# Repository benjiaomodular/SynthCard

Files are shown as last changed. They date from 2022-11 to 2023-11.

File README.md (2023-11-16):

# SynthCard
A businesscard-sized synthesizer module based on the Atari Punk Console.

I designed this project with the help of PCBWay. You can get a copy of these cards through the [PCBWay Shared Projects page](https://www.pcbway.com/project/shareproject/SynthCard_A_business_card_sized_synthesizer_module_84514b6e.html).

Schematics under `/KiCAD`. Gerber files under `/Fabrication`. Panel design under `/Inkscape`.

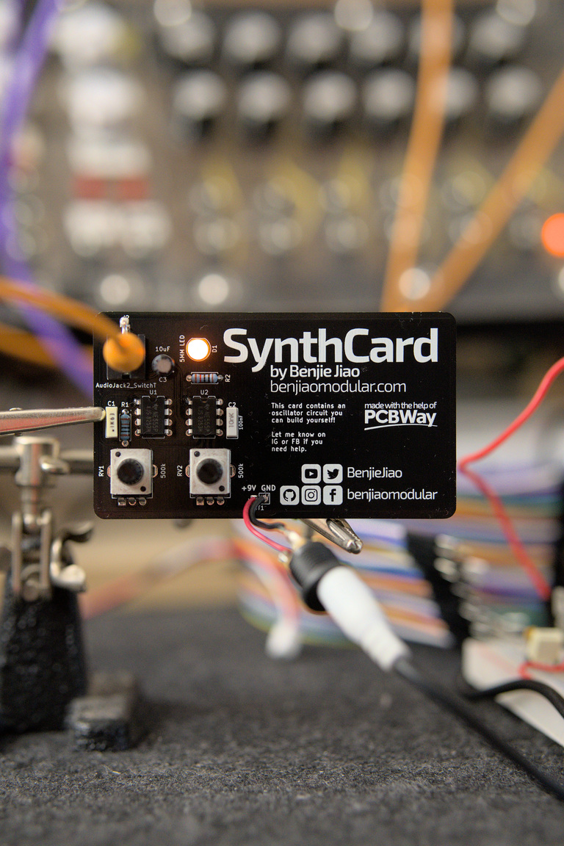
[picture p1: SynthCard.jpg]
A fully assembled SynthCard


## Features

This module produces a pulse/square wave at 9Vpp.

There are two knobs. Knob 1 controls the frequency. Knob 2 controls the pulse width.

The module can be powered using a 9V power supply. A battery should work too.

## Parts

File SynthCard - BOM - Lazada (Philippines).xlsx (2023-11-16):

Reference | Quantity | Value | Part Description | Cost | Lazada Link
BT1 | 1 | Battery | 9V Battery Snap or Barrel Connector | 64 | https://www.lazada.com.ph/products/10-pcs-3-terminal-soldering-21mm-x-55mm-female-power-jack-dc-socket-i3351654734.html
C1 | 1 | 10nF | Film Capacitors 50volts 0.01uF 10% LS 5mm | 6 | https://www.lazada.com.ph/products/polyester-film-capacitor-100v-mylar-022nf-033nf-047nf-056nf-068nf-1nf-22nf-27nf-33nf-39nf-47nf-68nf-10nf-15nf-22nf-33nf-39n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
C2 | 1 | 100nF | Film Capacitors 50volts 0.1uF 10% LS 5mm | 7 | https://www.lazada.com.ph/products/polyester-film-capacitor-100v-mylar-022nf-033nf-047nf-056nf-068nf-1nf-22nf-27nf-33nf-39nf-47nf-68nf-10nf-15nf-22nf-33nf-39n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
C3 | 1 | 10uF | Aluminum Electrolytic Capacitors - Radial Leaded 25volts 10uF | 4 | https://www.lazada.com.ph/products/aluminum-electrolytic-capacitor-10v-16v-25v-50v-01uf-022uf-047uf-1uf-22uf-33uf-47uf-68uf-10uf-22uf-33uf-47uf-100uf-220uf-33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
D1 | 1 | 5MM LED | Standard 5MM LED, any color will do | 40 | https://www.lazada.com.ph/products/20pcs-pack-3mm-5mm-led-light-diode-red-blue-green-white-yellow-2-pins-light-emitting-diode-3v-dc-dip-bead-lighting-f3-f5-3-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
J2 | 1 | 3.5mm Audio Jack | 3.5mm Mono Jack | 229 | https://www.lazada.com.ph/products/50pcs-35mm-female-audio-connector-3-pin-dip-headphone-jack-socket-mono-channel-pj-301m-wholesale-i385302560.html
R1 | 1 | 1k | 1/4W Resistor 1k ohms | 20 | https://www.lazada.com.ph/products/50pcs-1k-ohms-14w-metal-film-resistors-pack-1kohms-025w-watt-1-tolerance-1000r-electronic-part-ohm-5-bands-1-k-i857644178.h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
R2 | 1 | 10k | 1/4W Resistor 10k ohms | 20 | https://www.lazada.com.ph/products/50pcs-10k-ohms-14w-metal-film-resistors-pack-10-k-ohm-025w-watt-1-tolerance-10k-r-i864070514.html
RV1 RV2 | 2 | 500k | 500k Potentiometers. Also try 100k and 1M for different response and range. | 114 | https://www.lazada.com.ph/products/5set10pcs-rv09-vertical-1k-500k-ohm-adjustable-resistor-3pin-seal-potentiometer-for-arduino-with-knob-white-cap-5pcs5pcs-i3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
U1 U2 | 2 | NE555P | Timers & Support Products | 68 | https://www.lazada.com.ph/products/diymore-10pcs50pcs-lot-ne555-ne-555-ne555p-dip-8-dip-8-single-bipolar-timers-ic-chip-diymore-i1118752497.html
Wire | 1 | 24 AWG | 24 AWG Stranded Copper Wire | 10 | https://www.lazada.com.ph/products/stranded-solid-wire-22-24-awg-1meter-electrical-copper-cable-led-audio-diy-electronics-projects-electrical-i2205435323.html
 |  |  | TOTAL | 582

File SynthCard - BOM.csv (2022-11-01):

Reference | Quantity | Value | Footprint | Datasheet | Type | Manufacturers Name | Manufacturers Part Number | Part Description | Package
BT1 | 1 | Battery | Connector_PinHeader_2.54mm:PinHeader_1x02_P2.54mm_Vertical |  | Through-hole
C1 | 1 | 10nF | benjiaomodular:Capacitor_Rect_L7.2mm_W2.5mm_P5.00mm |  | Through-hole | KEMET | MMK5103K50J01L4BULK | Film Capacitors 50volts 0.01uF 10% LS 5mm
C2 | 1 | 100nF | benjiaomodular:Capacitor_Rect_L7.2mm_W2.5mm_P5.00mm |  | Through-hole | KEMET | MMK5104K50J01L4BULK | Film Capacitors 50volts 0.1uF 10% LS 5mm
C3 | 1 | 10uF | benjiaomodular:Capacitor_Radial_D5.0mm_P2.5mm |  | Through-hole | Nichicon | UVR1E100MDD1TD | Aluminum Electrolytic Capacitors - Radial Leaded 25volts 10uF
D1 | 1 | 5MM LED | LED_THT:LED_D5.0mm |  | Through-hole
J2 | 1 | AudioJack2_SwitchT | benjiaomodular:AudioJack_3.5mm |  | Through-hole | Tayda Electronics | PJ-3001F
R1 | 1 | 1k | benjiaomodular:Resistor_L6.3mm_D2.5mm_P7.62mm_Horizontal |  | Through-hole | KOA Speer | MF1/4DCT26A1001F
R2 | 1 | 10k | benjiaomodular:Resistor_L6.3mm_D2.5mm_P7.62mm_Horizontal |  | Through-hole | KOA Speer | MF1/4DC1002F
RV1 RV2 | 2 | 500k | benjiaomodular:Potentiometer_RV09 |  | Through-hole | Alpha (Taiwan) | RV09AF-40-20K-B500K
U1 U2 | 2 | NE555P | Package_DIP:DIP-8_W7.62mm | http://www.ti.com/lit/ds/symlink/ne555.pdf | Through-hole | Texas Instruments | NE555P | Timers & Support Products | PDIP-8

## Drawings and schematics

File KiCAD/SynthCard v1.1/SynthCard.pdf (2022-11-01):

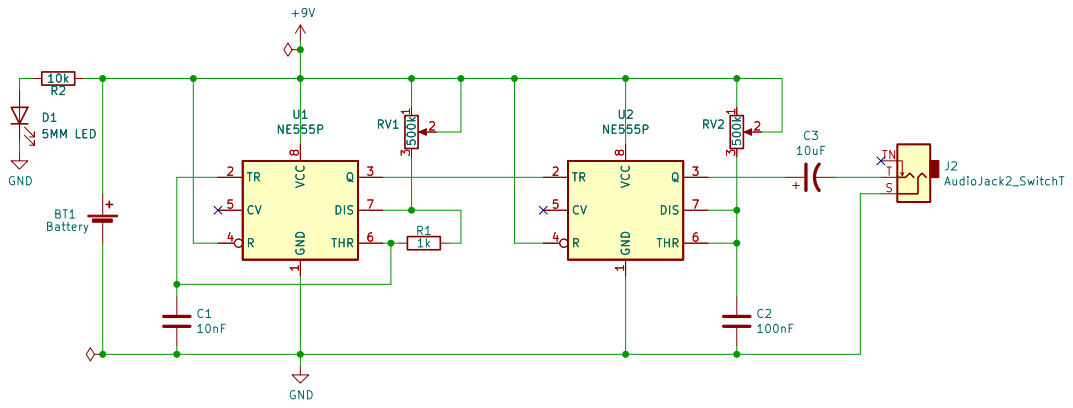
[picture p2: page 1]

File: SynthCard.kicad_sch Sheet: / GND

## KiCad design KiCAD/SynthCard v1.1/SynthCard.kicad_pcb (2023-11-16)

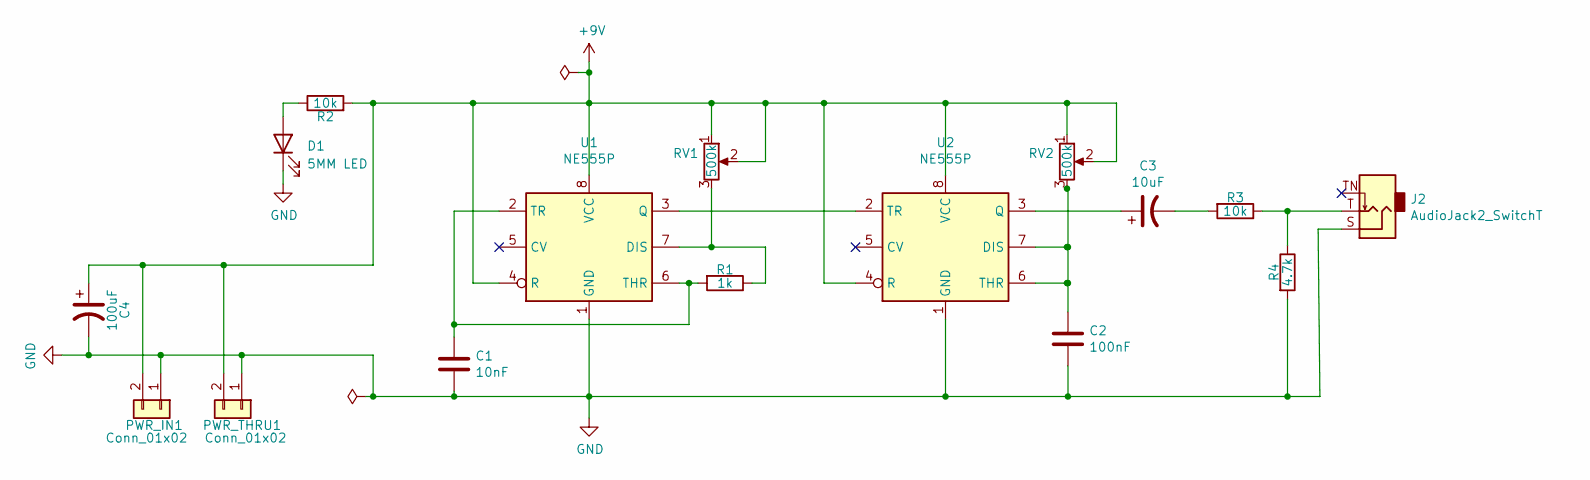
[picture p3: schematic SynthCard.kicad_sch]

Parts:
C1: 10nF; Capacitor_Rect_L7.2mm_W2.5mm_P5.00mm; Manufacturers Part Numb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 MMK5103K50J01L4BULK
C2: 100nF; Capacitor_Rect_L7.2mm_W2.5mm_P5.00mm; Manufacturers Part Numb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 MMK5104K50J01L4BULK
C3: 10uF; Capacitor_Radial_D5.0mm_P2.5mm; Manufacturers Part Numb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 UVR1E100MDD1TD
C4: 100uF; Capacitor_Radial_D5.0mm_P2.5mm; Manufacturers Part Numb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 UVR1E100MDD1TD
D1: 5MM LED; LED_D5.0mm
J2: AudioJack2_SwitchT; AudioJack_3.5mm; Manufacturers Part Numb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 PJ-3001F
PWR_IN1: Conn_01x02; PinSocket_1x02_P2.54mm_Vertical
PWR_THRU1: Conn_01x02; PinSocket_1x02_P2.54mm_Vertical
R1: 1k; Resistor_L6.3mm_D2.5mm_P7.62mm_Horizontal; Manufacturers Part Numb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 MF1/4DCT26A1001F
R2: 10k; Resistor_L6.3mm_D2.5mm_P7.62mm_Horizontal; Manufacturers Part Numb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 MF1/4DC1002F
R3: 10k; Resistor_L6.3mm_D2.5mm_P7.62mm_Horizontal; Manufacturers Part Numb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 MF1/4DCT26A1001F
R4: 4.7k; Resistor_L6.3mm_D2.5mm_P7.62mm_Horizontal; Manufacturers Part Numb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 MF1/4DCT26A1001F
RV1, RV2: 500k; Potentiometer_RV09; Manufacturers Part Numb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 RV09AF-40-20K-B500K
U1, U2: NE555P; DIP-8_W7.62mm; Manufacturers Part Numb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 NE555P

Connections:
+9V: C4.1, PWR_IN1.2, PWR_THRU1.2, R2.2, RV1.1, RV1.2, RV2.1, RV2.2, U1.4 (R), U1.8 (VCC), U2.4 (R), U2.8 (VCC)
GND: C1.2, C2.2, C4.2, D1.1 (K), J2.S, PWR_IN1.1, PWR_THRU1.1, R4.2, U1.1 (GND), U2.1 (GND)
unnamed: C1.1, R1.2, U1.2 (TR), U1.6 (THR)
unnamed: C2.1, RV2.3, U2.6 (THR), U2.7 (DIS)
unnamed: C3.1, U2.3 (Q)
unnamed: C3.2, R3.2
unnamed: D1.2 (A), R2.1
unnamed: J2.T, R3.1, R4.1
unnamed: R1.1, RV1.3, U1.7 (DIS)
unnamed: U1.3 (Q), U2.2 (TR)

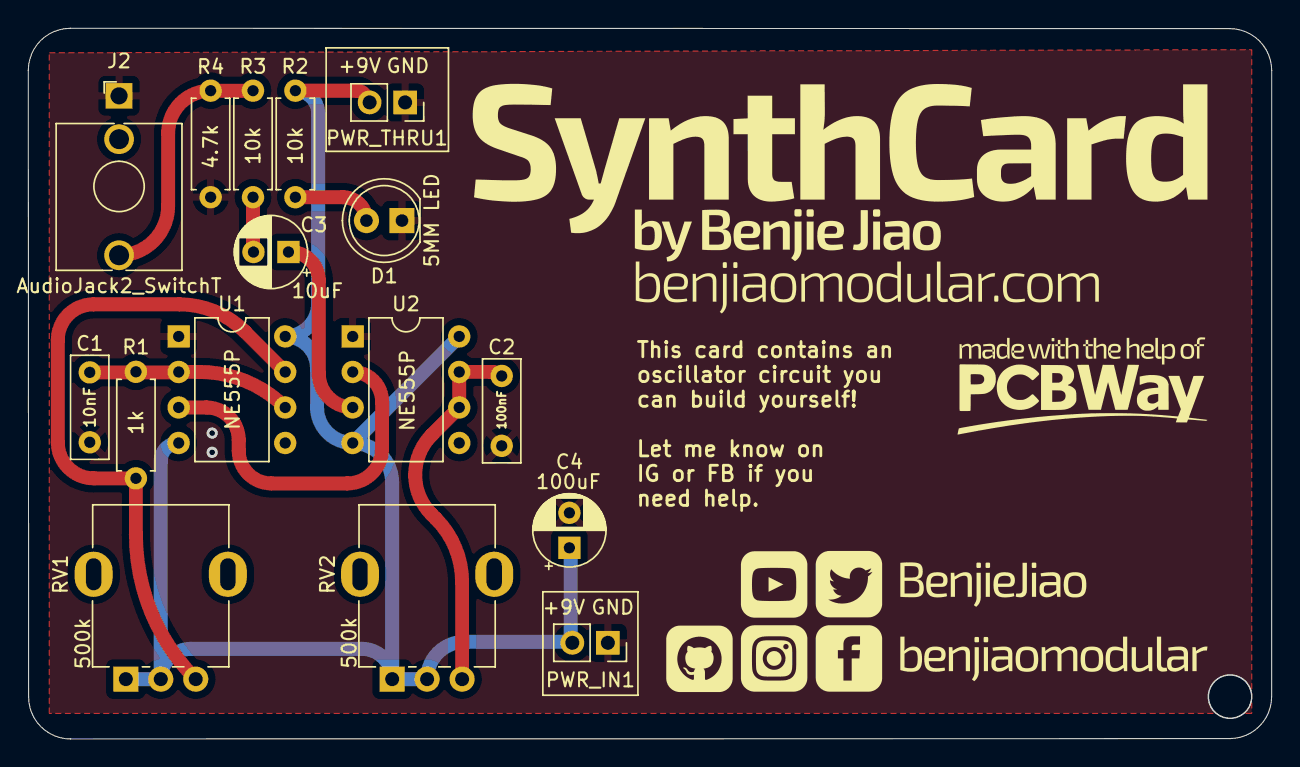
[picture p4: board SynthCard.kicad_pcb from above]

Board: 2 copper layers, 88.9 x 50.8 mm, 16 parts (0 on the bottom side), 10 nets.

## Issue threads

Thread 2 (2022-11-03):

Extra holes for mods

benjiao, 2022-11-03:
Add extra holes/pads to allow adding of extra components (ie. parallel LDR/Vactrols on pots, extra 9V pin outs.

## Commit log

2022-10-11 Tried inkscape
    [BusinessCardOscillator.kicad_pcb, BusinessCardOscillator.sch]
2022-11-01 First production version
    [BusinessCardOscillator.kicad_pcb, BusinessCardOscillator.sch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]
2022-11-01 Added readme
    [SynthCard.kicad_sch]
2022-11-01 Added working bom
    [SynthCard - BOM.csv, SynthCard.kicad_sch]
2022-11-08 Added BOM for Lazada
2022-11-08 removed csv from gitignore
    [SynthCard - BOM - Lazada (Philippines).csv]
2022-11-08 Update SynthCard - BOM - Lazada (Philippines).csv
    [SynthCard - BOM - Lazada (Philippines).csv]
2022-11-08 Added lazada link for BOM
    [SynthCard - BOM - Lazada (Philippines).xlsx]
2022-11-08 Added wires to bom
    [SynthCard - BOM - Lazada (Philippines).csv, SynthCard - BOM - Lazada (Philippines).xlsx]
2023-11-16 ADded build guide
    [SynthCard - BOM - Lazada (Philippines).xlsx, SynthCard.kicad_pcb, SynthCard.kicad_sch]
